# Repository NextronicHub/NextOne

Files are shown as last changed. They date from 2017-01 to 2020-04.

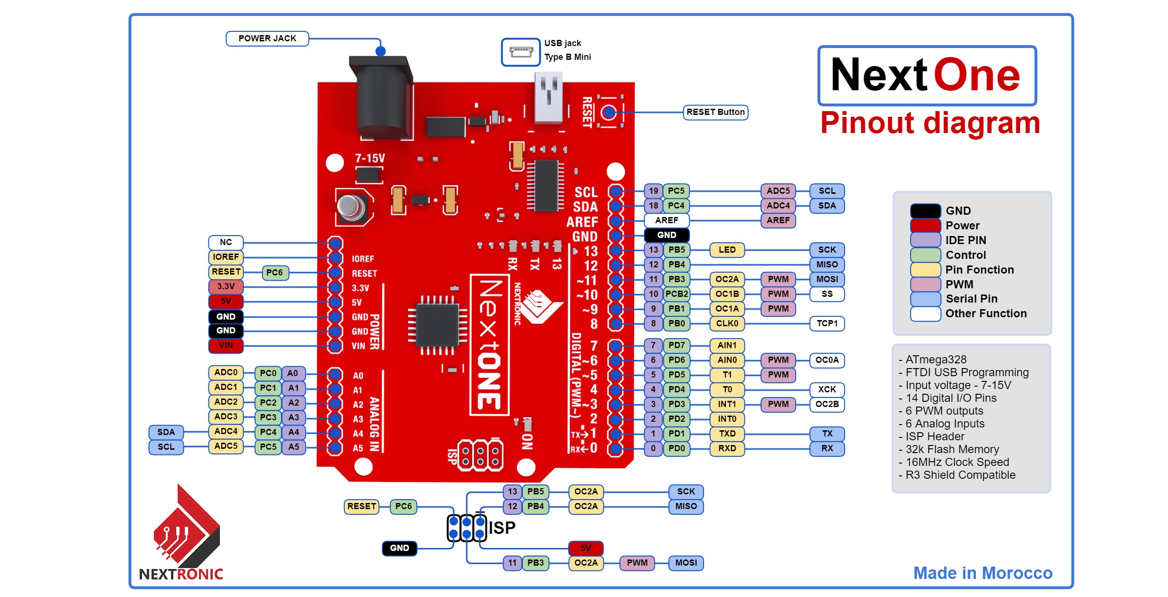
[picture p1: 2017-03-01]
Documentation/NextOne_pinout.jpg

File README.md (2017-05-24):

# Nextronic NextOne

NextOne is one of the best board to start your personal electronics projects, it is built upon the famous ARDUINO UNO, so it shares its simplicity and its flexibility. NextOne can be programmed over a USB Mini-B cable using the Arduino IDE: Just plug in the board, select “Arduino UNO” from the board menu and you’re ready to upload code. NextOne has all of the hardware peripherals like the Arduino. NextOne is an R3 shield compatibility so you can plug all the Arduino shields.
NextOne is built upon the [Arduino UNO](https://www.arduino.cc/en/Main/ArduinoBoardUno) and the sparkfun [RedBoard](https://www.sparkfun.com/products/13975).

## Features:

ATmega328 microcontroller with Optiboot (UNO) Bootloader<br />
Input voltage - 7-15V<br />
0-5V outputs<br />
14 Digital I/O Pins (6 PWM outputs)<br />
6 Analog Inputs<br />
I2C, UART and SPI<br />
32k Flash Memory<br />
16MHz Clock Speed<br />
All SMD Construction<br />
R3 Shield Compatible<br />
<br /><br />
[FTDI driver](http://www.ftdichip.com/Drivers/VCP.htm)

Nextronic Product page:[NextOne](http://nextronic.ma/product/nextone/).

you can by it at: [makershop.ma](http://makershop.ma/).

## Repository Contents

/Hardware - Design files (.brd, .sch)  
/Firmware - bootloader  
/Documentation - datasheet and examples

## Product Versions

NextOne_V1 first release

## License Information

The hardware is released under [Creative Commons ShareAlike 4.0 International](https://creativecommons.org/licenses/by-sa/4.0/).

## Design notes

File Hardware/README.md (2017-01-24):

#  Nextronic NextOne Design Files

The .sch and .brd files are Eagle CAD schematic and PCB design files from Nextronic.  
Eagle PCB Design | Schematic Editor, Layout Editor & Autorouter can be found at http://www.autodesk.com/products/eagle.

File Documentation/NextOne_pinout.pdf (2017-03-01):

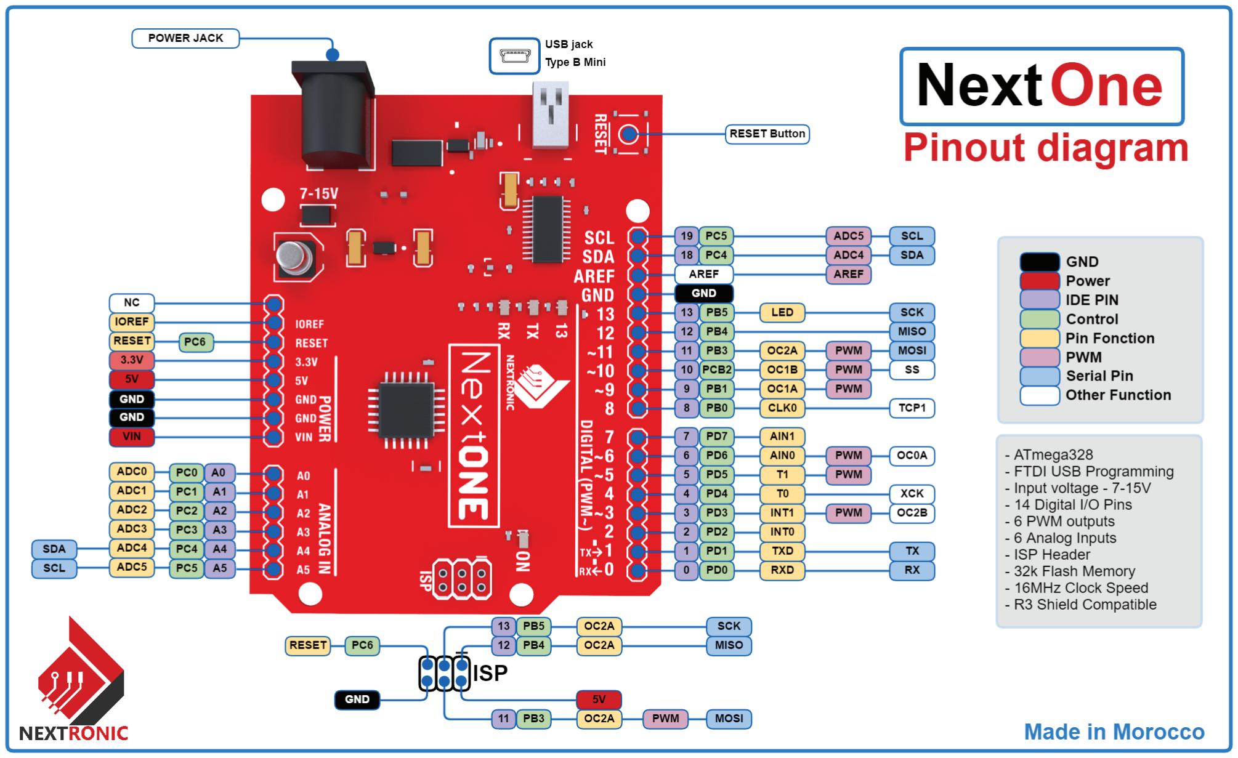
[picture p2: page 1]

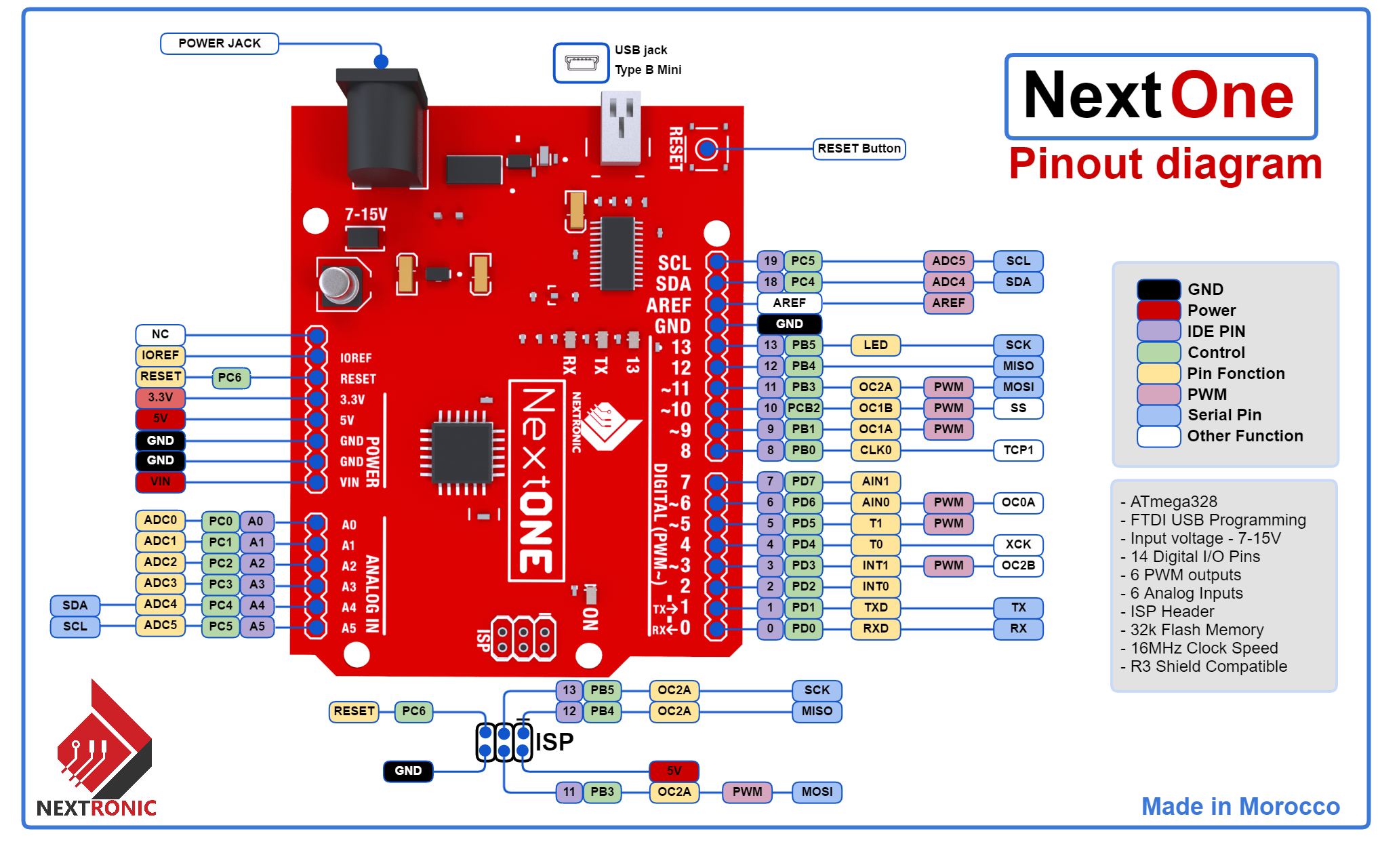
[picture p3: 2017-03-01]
Documentation/NextOne_pinout.png

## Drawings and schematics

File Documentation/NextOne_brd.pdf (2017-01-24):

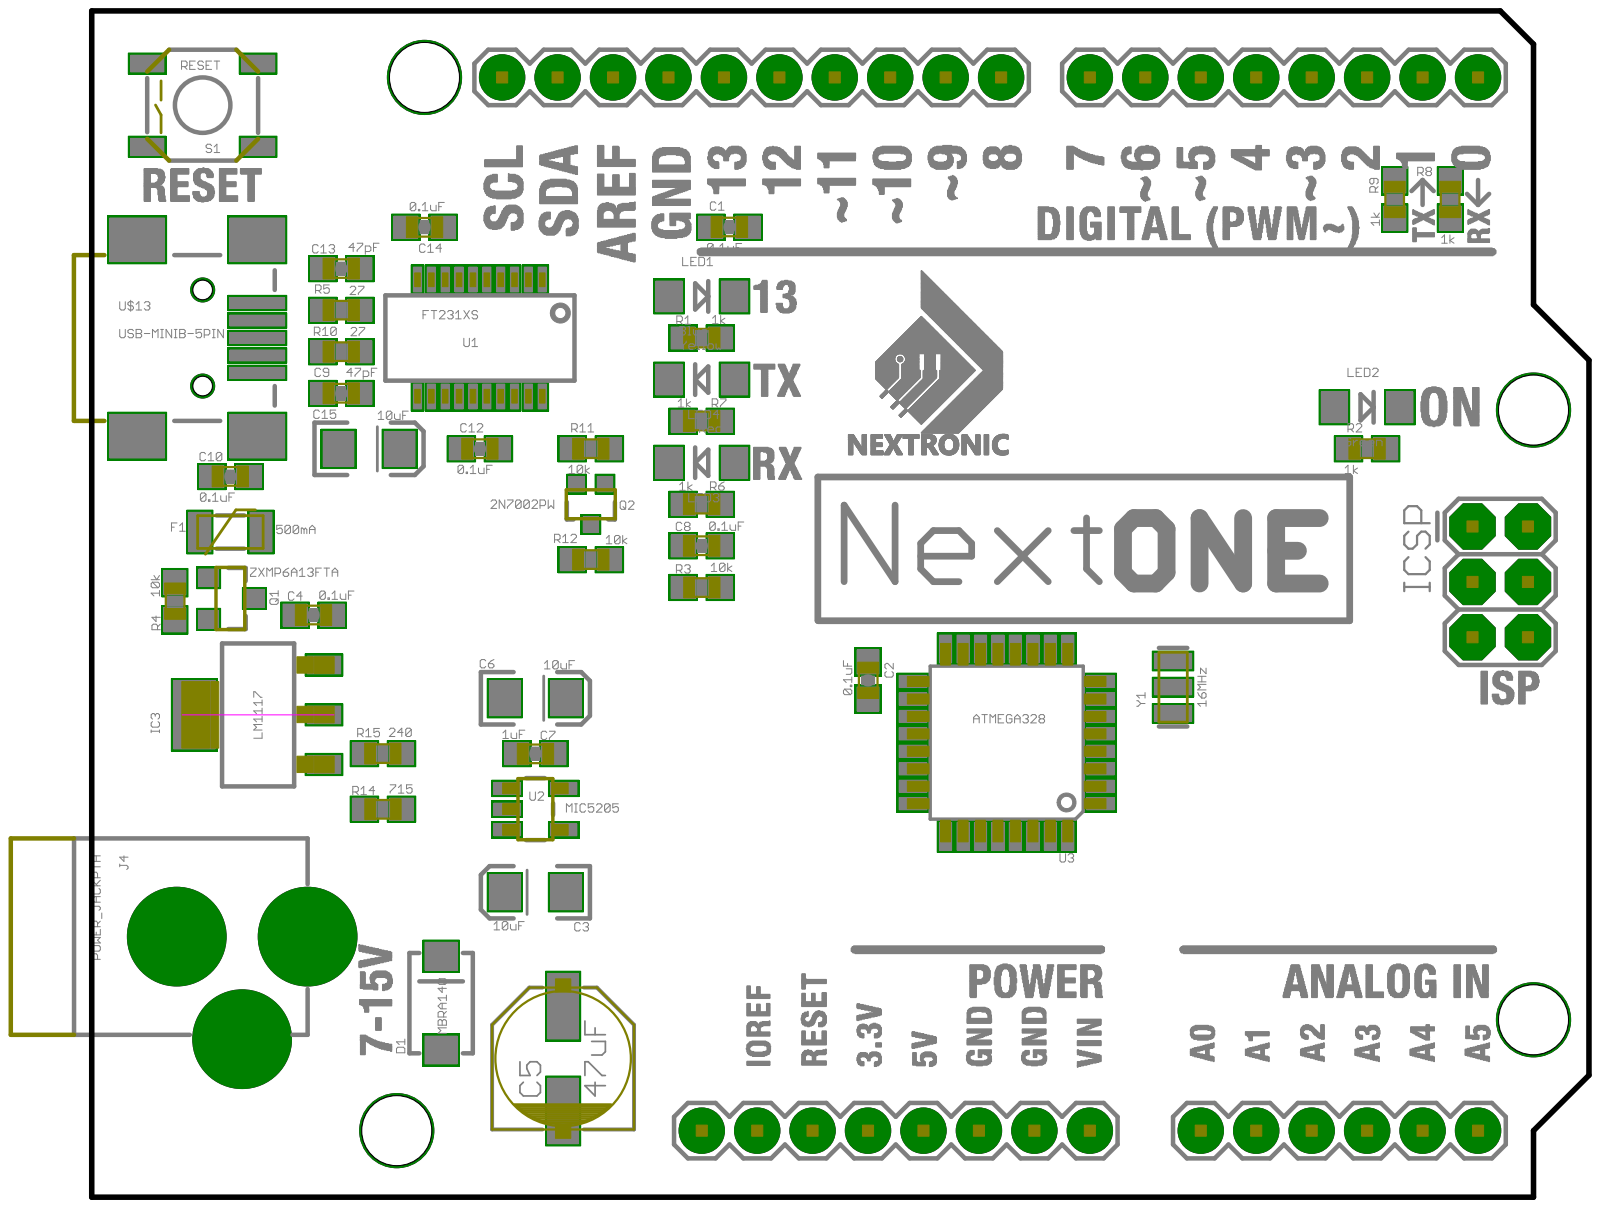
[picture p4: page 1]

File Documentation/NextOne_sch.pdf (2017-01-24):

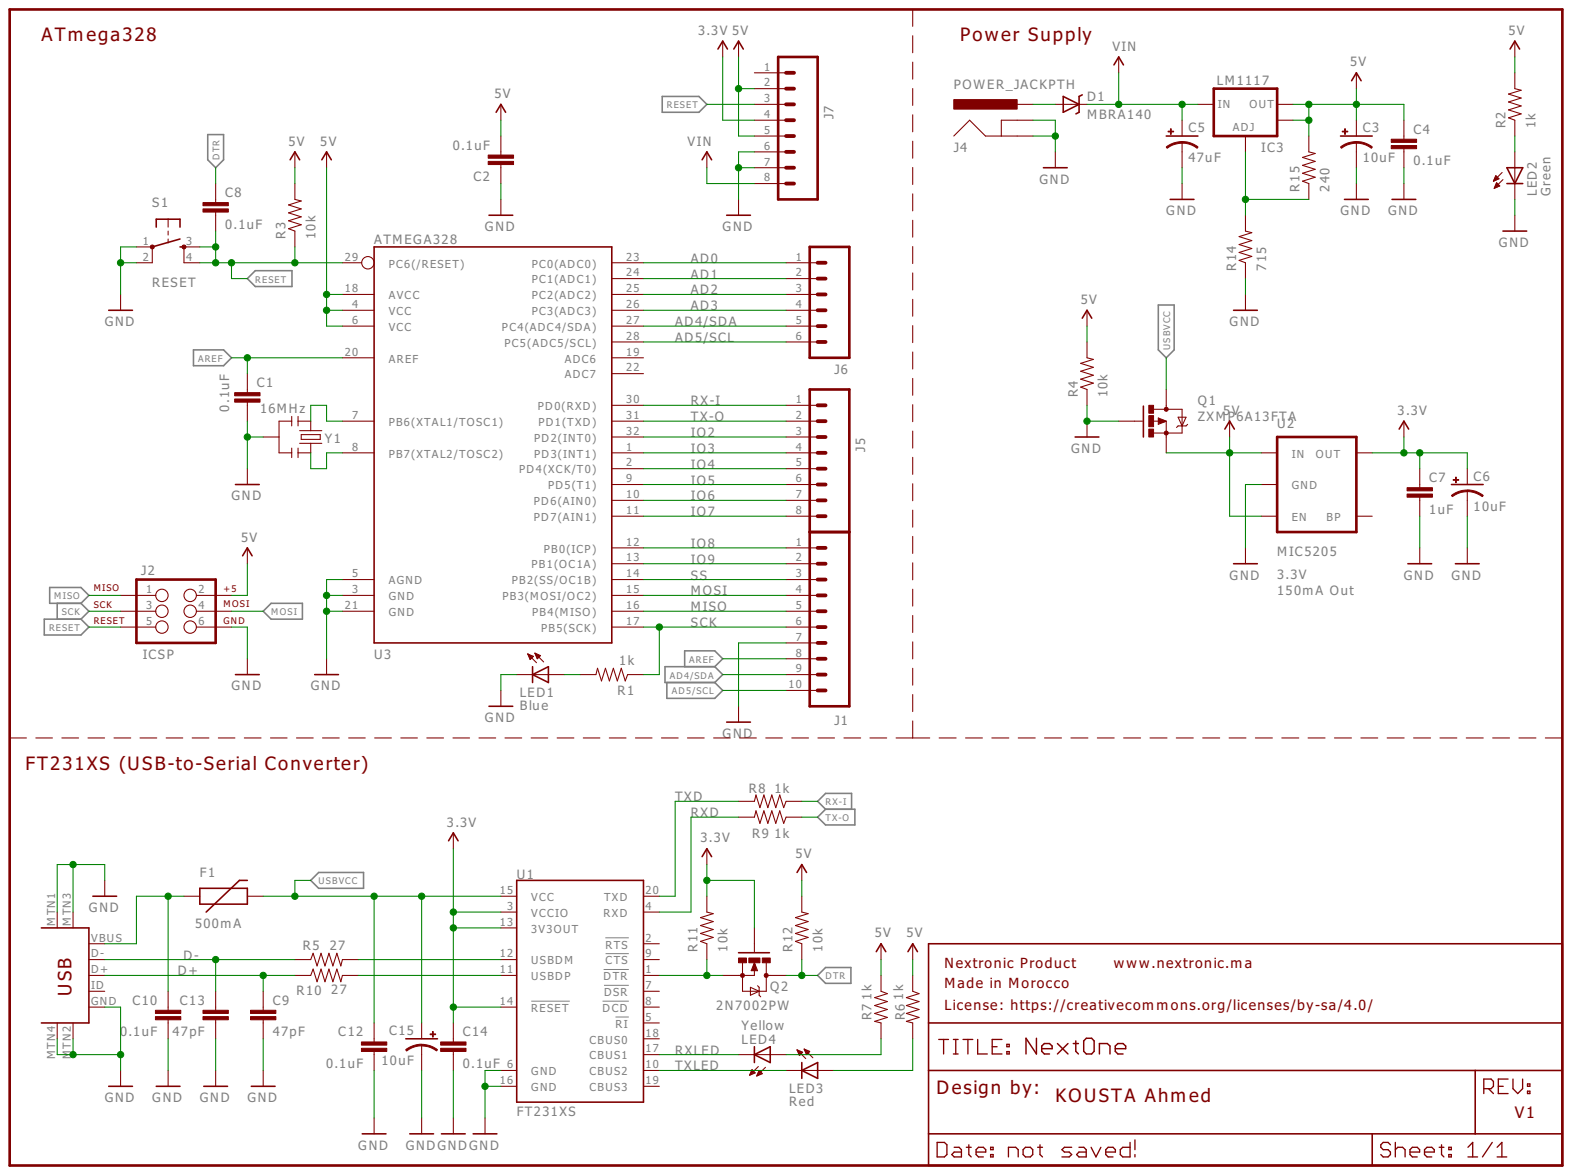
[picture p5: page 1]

18 | | AD0 AD1 AD2 AD3 AD4/SDA 2

AREF 20 | AD5/SCL 6

FT231XS (USB-to-Serial Converter)

License: https://creativecommons.org/licenses/by-sa/4.0/

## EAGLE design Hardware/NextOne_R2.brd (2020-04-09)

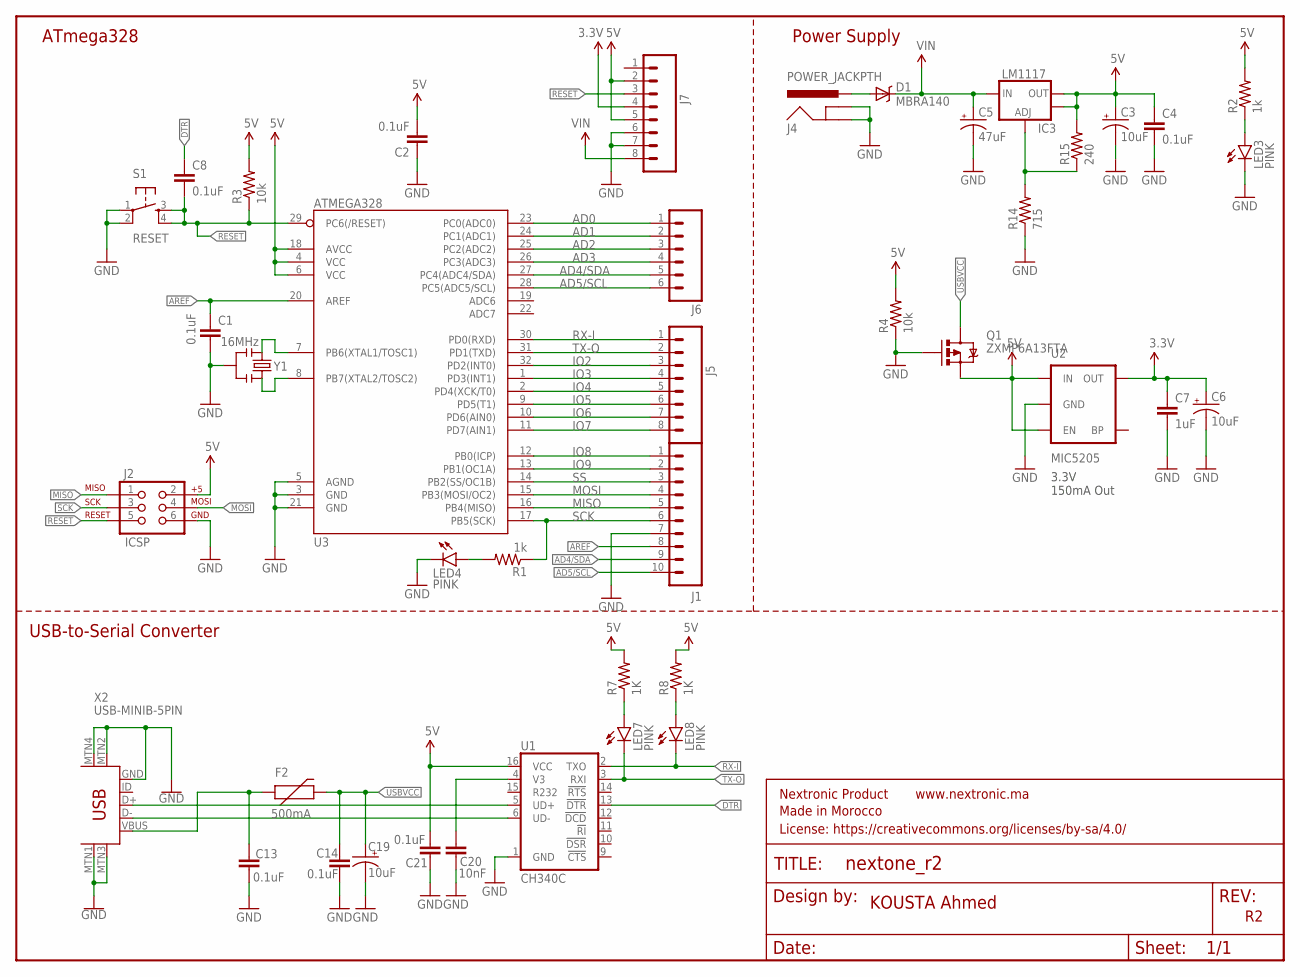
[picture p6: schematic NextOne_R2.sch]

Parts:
C1, C2, C4, C8: 0.1uF; 0603-CAP
C3, C6, C19: 10uF; EIA3216
C5: 47uF; PANASONIC_D; MPN EEE1CA470SP
C7: 1uF; 0603-CAP; MPN 0805B104K500CT
C13, C14, C21: 0.1uF; 0603
C20: 10nF; 0603
D1: MBRA140; SMA-DIODE; MPN B140-13-F
F2: 500mA; PTC-1206
FRAME1: FRAME-LETTER; CREATIVE_COMMONS
IC3: LM1117; SOT223-ALT1; MPN LD1117S33TR
J1: M10SILK_FEMALE_PTH; 1X10
J2: ICSP; 2X3
J4: POWER_JACKPTH; POWER_JACK_PTH
J5, J7: M08; 1X08_ROUND
J6: M06SILK_FEMALE_PTH; 1X06
LED3, LED4, LED7, LED8: PINK; LED-1206@1
Q1: ZXMP6A13FTA; SOT23-3; MPN ZXMP6A13FTA
R1, R2: 1k; 0603-RES
R3, R4: 10k; 0603-RES
R7, R8: 1K; 0603-RES; MPN CRCW25121K00JNEG
R14: 715; 0603-RES
R15: 240; 0603-RES
S1: RESET; TACTILE_SWITCH_SMD
U1: CH340C; SO016
U2: MIC5205; SOT23-5
U3: ATMEGA328; TQFP32-08; MPN ATMEGA328P-AN
X2: USB-MINIB-5PIN; USB-MINIB
Y1: 16MHz; RESONATOR-SMD

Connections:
3.3V: C6.A (+), C7.1, J7.4, U2.5 (OUT)
5V: C2.2, C3.A (+), C4.1, C21.1, IC3.2 (OUT), IC3.4 (OUT), J2.2, J7.2, J7.5, Q1.2 (S), R2.2, R3.2, R4.2, R7.2, R8.2, R15.2, U1.16 (VCC), U2.1 (IN), U2.3 (EN), U3.4 (VCC), U3.6 (VCC), U3.18 (AVCC)
AD0: J6.1, U3.23 (PC0(ADC0))
AD1: J6.2, U3.24 (PC1(ADC1))
AD2: J6.3, U3.25 (PC2(ADC2))
AD3: J6.4, U3.26 (PC3(ADC3))
AD4/SDA: J1.9, J6.5, U3.27 (PC4(ADC4/SDA))
AD5/SCL: J1.10, J6.6, U3.28 (PC5(ADC5/SCL))
AREF: C1.1, J1.8, U3.20 (AREF)
D+1: U1.5 (UD+), X2.D+
D-1: U1.6 (UD-), X2.D-
DTR: C8.1, U1.13 (!DTR)
GND: C1.2, C2.1, C3.C (-), C4.2, C5.-, C6.C (-), C7.2, C13.2, C14.2, C19.-, C20.2, C21.2, J1.7, J2.6, J4.GND, J4.GNDBREAK, J7.6, J7.7, LED3.C, LED4.C, Q1.1 (G), R4.1, R14.1, S1.1, S1.2, U1.1 (GND), U2.2 (GND), U3.3 (GND), U3.5 (AGND), U3.21 (GND), X2.GND, X2.MTN1 (MTN2), X2.MTN2 (MTN3), X2.MTN3 (MTN1), X2.MTN4, Y1.2
IO2: J5.3, U3.32 (PD2(INT0))
IO3: J5.4, U3.1 (PD3(INT1))
IO4: J5.5, U3.2 (PD4(XCK/T0))
IO5: J5.6, U3.9 (PD5(T1))
IO6: J5.7, U3.10 (PD6(AIN0))
IO7: J5.8, U3.11 (PD7(AIN1))
IO8: J1.1, U3.12 (PB0(ICP))
IO9: J1.2, U3.13 (PB1(OC1A))
MISO: J1.5, J2.1, U3.16 (PB4(MISO))
MOSI: J1.4, J2.4, U3.15 (PB3(MOSI/OC2))
unnamed: LED4.A, R1.2
unnamed: LED3.A, R2.1
unnamed: U3.7 (PB6(XTAL1/TOSC1)), Y1.1
unnamed: U3.8 (PB7(XTAL2/TOSC2)), Y1.3
unnamed: D1.A, J4.PWR
unnamed: LED7.A, R7.1
unnamed: LED8.A, R8.1
unnamed: C20.1, U1.4 (V3)
unnamed: IC3.1 (ADJ), R14.2, R15.1
RESET: C8.2, J2.5, J7.3, R3.1, S1.3, S1.4, U3.29 (PC6(/RESET))
RX-I: J5.1, LED8.C, U1.2 (TXO), U3.30 (PD0(RXD))
SCK: J1.6, J2.3, R1.1, U3.17 (PB5(SCK))
SS: J1.3, U3.14 (PB2(SS/OC1B))
TX-O: J5.2, LED7.C, U1.3 (RXI), U3.31 (PD1(TXD))
USBVCC: C14.1, C19.+, F2.2, Q1.3 (D)
VIN: C5.+, D1.C, IC3.3 (IN), J7.8
VUSB1: C13.1, F2.1, X2.VBUS

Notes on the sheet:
Power Supply
ATmega328
3.3V 150mA Out
KOUSTA Ahmed
USB-to-Serial Converter

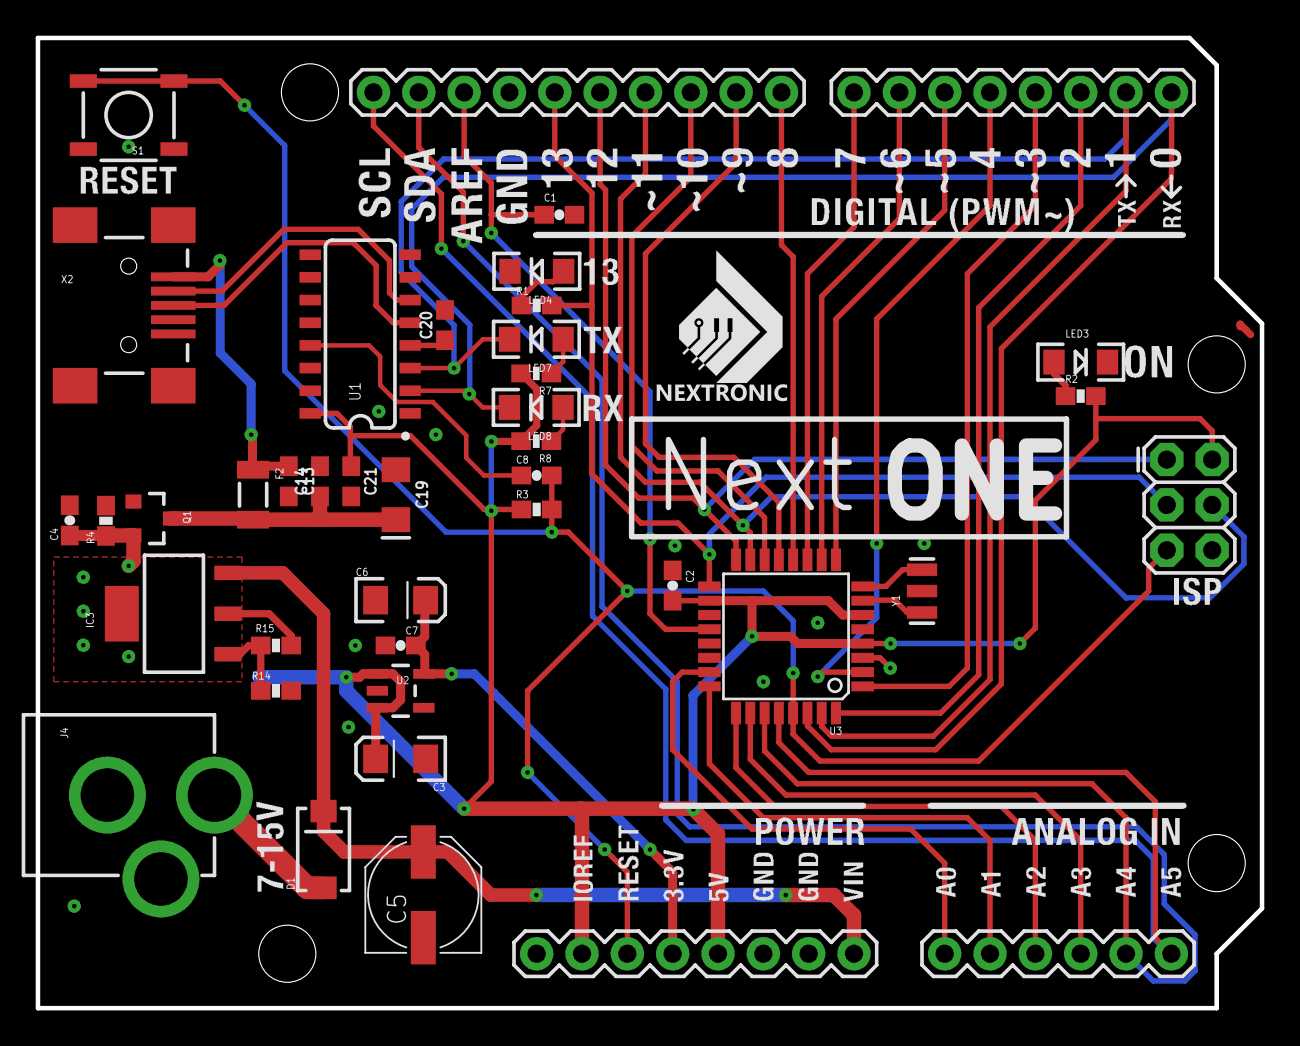
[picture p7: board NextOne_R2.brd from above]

Board: 2 copper layers, 68.6 x 54.4 mm, 42 parts (0 on the bottom side), 40 nets.

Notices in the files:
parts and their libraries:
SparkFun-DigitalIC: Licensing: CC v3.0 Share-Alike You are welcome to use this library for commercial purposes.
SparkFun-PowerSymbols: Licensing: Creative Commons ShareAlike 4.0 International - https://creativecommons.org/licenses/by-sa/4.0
